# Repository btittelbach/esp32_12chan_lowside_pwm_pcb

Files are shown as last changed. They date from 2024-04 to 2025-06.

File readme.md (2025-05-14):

# esp32_12chan_lowside_pwm_pcb

Open Hardware PCB designed to drive 12 low-side PWM channels.

It's designed to work with e.g. WLED firmware and can drive up to 4 RGB LED strips.

You can however use it for whatever you want.
Free-wheeling diodes were added, in case someone wants to use it to drive bigger inductive loads.

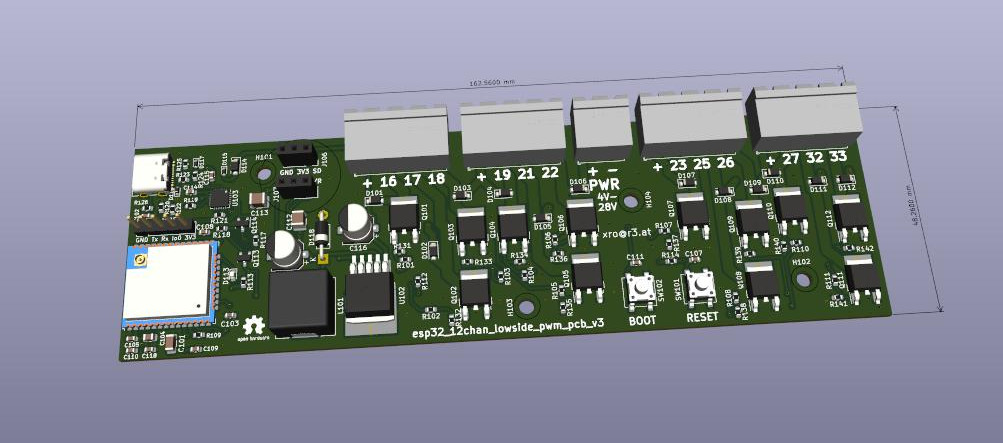
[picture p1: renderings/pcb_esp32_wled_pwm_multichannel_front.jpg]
img_front


[Schematic](renderings/pcb_esp32_wled_pwm_multichannel.pdf)

## Power

### Input

Power by USB for easy flashing.

Or power via screw-terminal: DC from 4V up to 28V.

#### optional Sound-Reactive Microphone Input

- I2S SD pin: gpio4
- I2S WS pin: gpio14
- I2S SCK pin: gpio13

### Output

The four screw terminals each group VDD as well as 4 GPIO controlled PWM-channels to GND.

- terminal 1: VDD, gpio16, gpio17, gpio18
- terminal 2: VDD, gpio19, gpio21, gpio22
- terminal 3: VDD, gpio23, gpio25, gpio26
- terminal 4: VDD, gpio27, gpio32, gpio33

## Firmware

for easy use, flash WLED-ESP32 and use web-interface to configure
4 "LEDS" as RGB-Strips with GPIO pins listed above.

## Manufacturing

the board was not designed to minimize costs, but for durability.

The folder `esp32_12chan_lowside_pwm_pcb_v3` includes all manufacturing files and information,
so you should easily be able to order your own.

See [fabrication_data.md](esp32_12chan_lowside_pwm_pcb_v3/fabrication_data.md) for specs often asked in order to get a quote.

### Expensive Parts
- the MosFETs
- the choosen ESP32, though you may choose a version with less Flash
- the QFN USB to UART bridge
- the buck regulator

### Costs

big price hike in 2025:

- per PCB the parts cost roughly 23 USD
- production+assembly+parts come to roughly 54 USD per PCB

## License

This project is licensed under the CERN OH License - see the [LICENSE](LICENSE.txt) file for details

## Photos

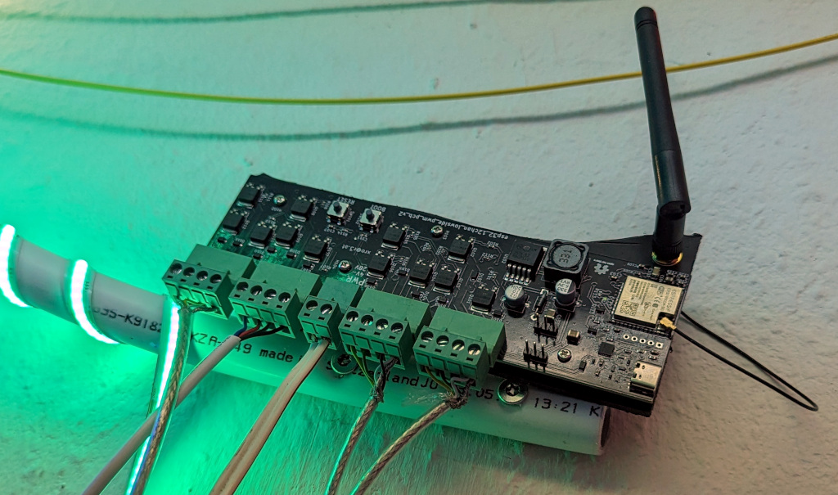
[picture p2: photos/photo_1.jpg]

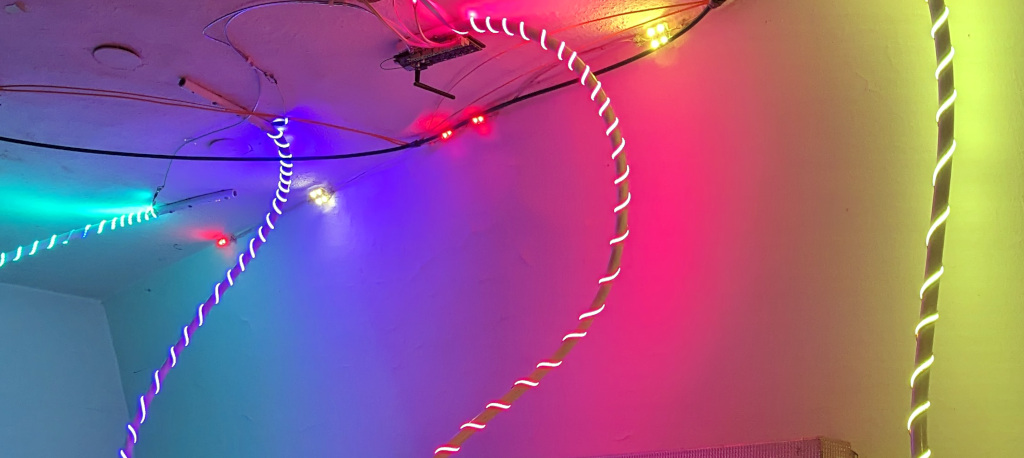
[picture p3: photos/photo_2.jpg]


## Ordering

List of PCB Suppliers which one-click ordering for the board. (so far only one)

- [PCBWay](https://www.pcbway.com/project/shareproject/W18448ASS50_esp32_12chan_wled_pwm_v3_13ab729a.html)

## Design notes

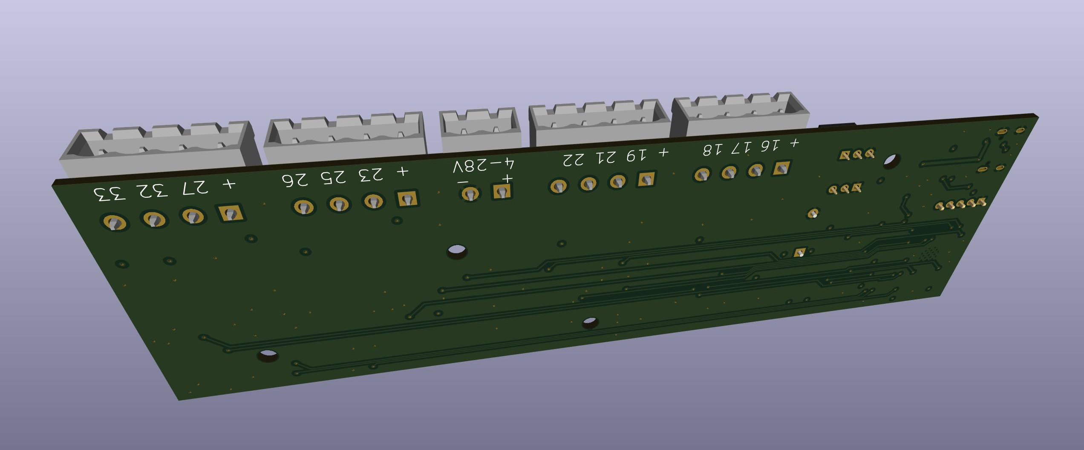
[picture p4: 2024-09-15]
renderings/pcb_esp32_wled_pwm_multichannel_bottom.jpg

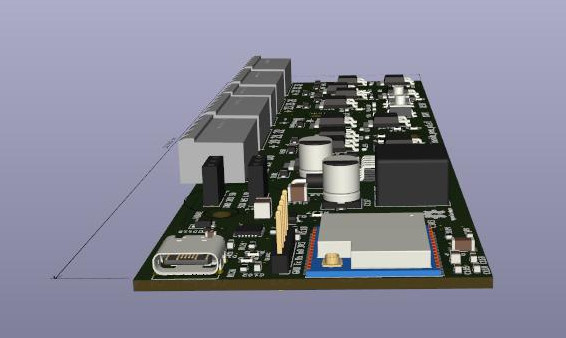
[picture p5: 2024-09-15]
renderings/pcb_esp32_wled_pwm_multichannel_side.jpg

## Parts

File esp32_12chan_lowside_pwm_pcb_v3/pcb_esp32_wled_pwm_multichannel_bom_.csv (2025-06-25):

Reference | Value | Qty | DNP | DNF | Distributor | LCSC | MF | MP | SMD | TH
C101,C102,C103,C104,C105,C106 | CL05A106MQ5NUN | 6 |  |  | LCSC | C15525 | Samsung Electro-Mechanics | CL05A106MQ5NUN | 1
C107 | 100nF/50V | 1 |  |  | LCSC | C42998 | FH | 0603F104M500NT | 1
C111 | 1nF/50V | 1 |  |  | LCSC | C100040 | YAGEO | CC0603KRX7R9BB102 | 1
C112,C113 | 22uF/25V(10%) | 2 |  |  | LCSC | C337455 | Taiyo Yuden | TMK325B7226KM-TR | 1
C116 | 100µF/50V | 1 |  |  | LCSC | C311622 | Lelon | VZT101M1HTR-0607 | 1
C117 | 330µF/6.3V | 1 |  |  | LCSC | C74623 | RVT0J331M0607 | ROQANG | 1
D101,D102,D103,D104,D105,D106,D107,D108,D109,D110,D111,D112,D114 | D_Schottky | 13 |  |  | LCSC | C496544 | Shanghai Prisemi Elec | PSBD1DF40V2L | 1
D113 | GREEN_LED | 1 |  |  | LCSC | C89809 | Foshan NationStar Optoelectronics | NCD0603C3 | 1 | 0
D115,D116,D117 | LESD5D5.0CT1G | 3 |  |  | LCSC | C383211 | LRC | LESD5D5.0CT1G | 1 | 0
D118 | 1N5819 | 1 |  |  |  |  |  |  | 0 | 1
J101,J102,J103,J104 | WJ2EDGRC-5.08-4P | 4 |  |  | LCSC | C8446 | Ningbo Kangnex Elec | WJ2EDGRC-5.08-4P | 0 | 1
J105 | Conn_01x05_Male | 1 |  | DNF |  |  |  |  | 0 | 0
J106,J107 | Conn_01x03_Female | 2 |  |  | LCSC | C358717 | generic | PinHeader,Feamle,P=2.54mm,3Pin,1Row,1A | 0 | 1
J108 | Conn_01x02_Female | 1 |  |  | LCSC | C3697 | Ningbo Kangnex Elec | WJ2EDGRC-5.08-2P | 0 | 1
J109 | USB_C_Receptacle_USB2.0 | 1 |  |  | LCSC | C165948 | Korean Hroparts Elec | TYPE-C-31-M-12 | 1 | 0
L101 | 330µH | 1 |  |  | LCSC | C2929508 | SHOU HAN | CYH127-330UH | 1
Q101,Q102,Q103,Q104,Q105,Q106,Q107,Q108,Q109,Q110,Q111,Q112 | IRLR8743TRPBF | 12 |  |  | LCSC | C3040285 | Infineon Technologies | IRLR8743TRPBF | 1 | 0
Q113,Q114 | Q_NPN_Darlington_BEC | 2 |  |  | LCSC | C164885 | JIANGSU CHANGJIANG ELECTRONICS | SS8050 | 1
R101,R102,R103,R104,R105,R106,R107,R108,R109,R110,R111,R112 | 91(1%) | 12 |  |  |  |  |  |  | 1
R113 | 68Ω/1% | 1 |  |  | LCSC | C126362 | YAGEO | RC0603FR-0768RL | 1 | 0
R114,R117,R118,R121,R131,R132,R133,R134,R135,R136,R137,R138,R139,R140,R141,R142 | 10K(5%) | 16 |  |  |  |  |  |  | 1
R119 | 2K(5%) | 1 |  |  |  |  |  |  | 1 | 0
R120 | 47K(5%) | 1 |  |  |  |  |  |  | 1
R122 | 22K(1%) | 1 |  |  |  |  |  |  | 1
R123,R124 | 22(1%) | 2 |  |  |  |  |  |  | 1
R125,R126 | 5k1 (5%) | 2 |  |  |  |  |  |  | 1 | 0
SW101,SW102 | SW_Push | 2 |  |  | LCSC | C86708 | Omron Electronics | B3SL-1022P | 1
U101 | ESP32-WROOM-32U | 1 |  |  | LCSC | C328062 | Espressif | ESP32-WROOM-32U | 1
U102 | LM2575-3.3BU | 1 |  |  | LCSC | C70337 | onsemi | LM2575D2T-3.3R4G | 1
U103 | CP2102N-Axx-xQFN24 | 1 |  |  | LCSC | C969151 | Silicon Labs | CP2102N-A02-GQFN24R | 1 | 0

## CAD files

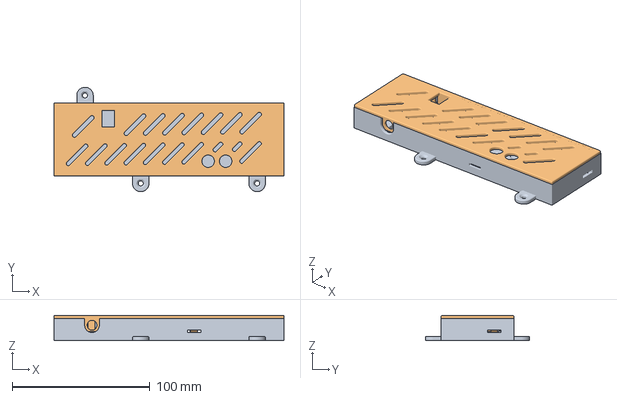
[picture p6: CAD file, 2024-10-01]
enclosure/wled_pwm_multichannel_enclosure_variant_microphone_hole.3mf
167.1 x 75.9 x 18.4 mm

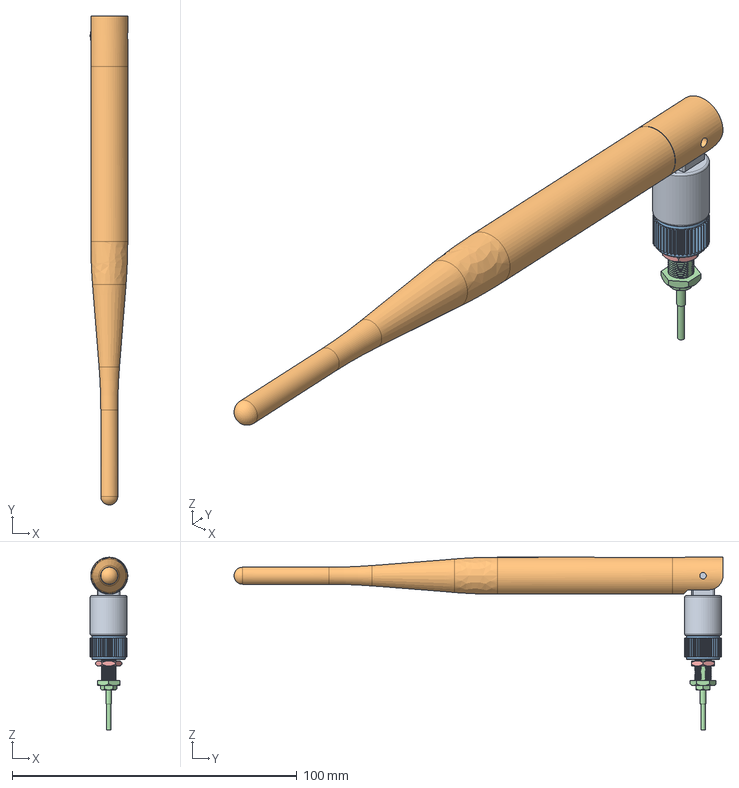
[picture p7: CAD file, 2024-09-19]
enclosure/sma_antenna.FCStd
13.2 x 171.8 x 60.6 mm
antenna_part_2 v2
antenna_part_1 v4
antenna_part_3 v2
SMA_connector_part_1 v3
SMA_connector_part_2 v1

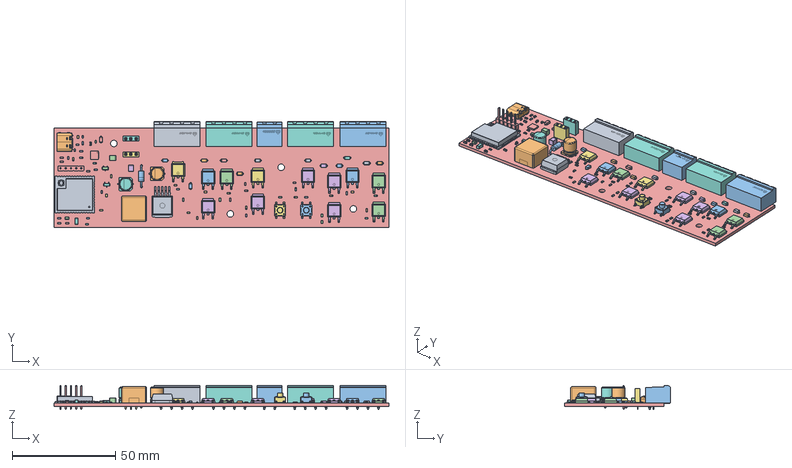
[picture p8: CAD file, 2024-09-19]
enclosure/pcb_esp32_wled_pwm_multichannel_kicad_export.FCStd
162.6 x 51.2 x 11.8 mm
D_SOD_123F
R_0603_1608Metric
SW_SPST_PTS647Sx50
CQ assembly
R_0603_1608Metric002
CQ assembly001
PinSocket_1x03_P254mm_Vertical
PinSocket_1x03_P254mm_Vertical001
R_0603_1608Metric004
R_0603_1608Metric006
D_SOD_523
R_0603_1608Metric008
D_SOD_123F001
CQ assembly002
R_0603_1608Metric010
CP_Elec_63x77
R_0603_1608Metric012
R_0603_1608Metric014
2EDGRC-5.08-04P-14-100AH
C_0603_1608Metric
R_0603_1608Metric016
CQ assembly003
R_0603_1608Metric018
R_0603_1608Metric020
D_SOD_123F002
R_0603_1608Metric022
CQ assembly004
D_SOD_524
C_0603_1608Metric002
R_0603_1608Metric024
R_0603_1608Metric026
C_1206_3216Metric
R_0603_1608Metric028
D_SOD_123F003
D_SOD_123F004
R_0603_1608Metric030
R_0603_1608Metric032
CQ assembly005
C_0603_1608Metric004
C_0603_1608Metric006
C_0603_1608Metric008
CP_Elec_63x078
D_SOD_123F005
R_0603_1608Metric034
R_0603_1608Metric036
CQ assembly006
CQ assembly007
2EDGRC-5.08-04P-14-100AH002
D_SOD_525
L_SXN_SMDRI127
R_0603_1608Metric038
R_0603_1608Metric040
C_0603_1608Metric010
C_0603_1608Metric012
CQ assembly008
C_0603_1608Metric014
C_0603_1608Metric016
R_0603_1608Metric042
CQ assembly009
C_0805_2012Metric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

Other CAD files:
enclosure/wled_pwm_multichannel_enclosure.FCStd
enclosure/wled_pwm_multichannel_enclosure.3mf

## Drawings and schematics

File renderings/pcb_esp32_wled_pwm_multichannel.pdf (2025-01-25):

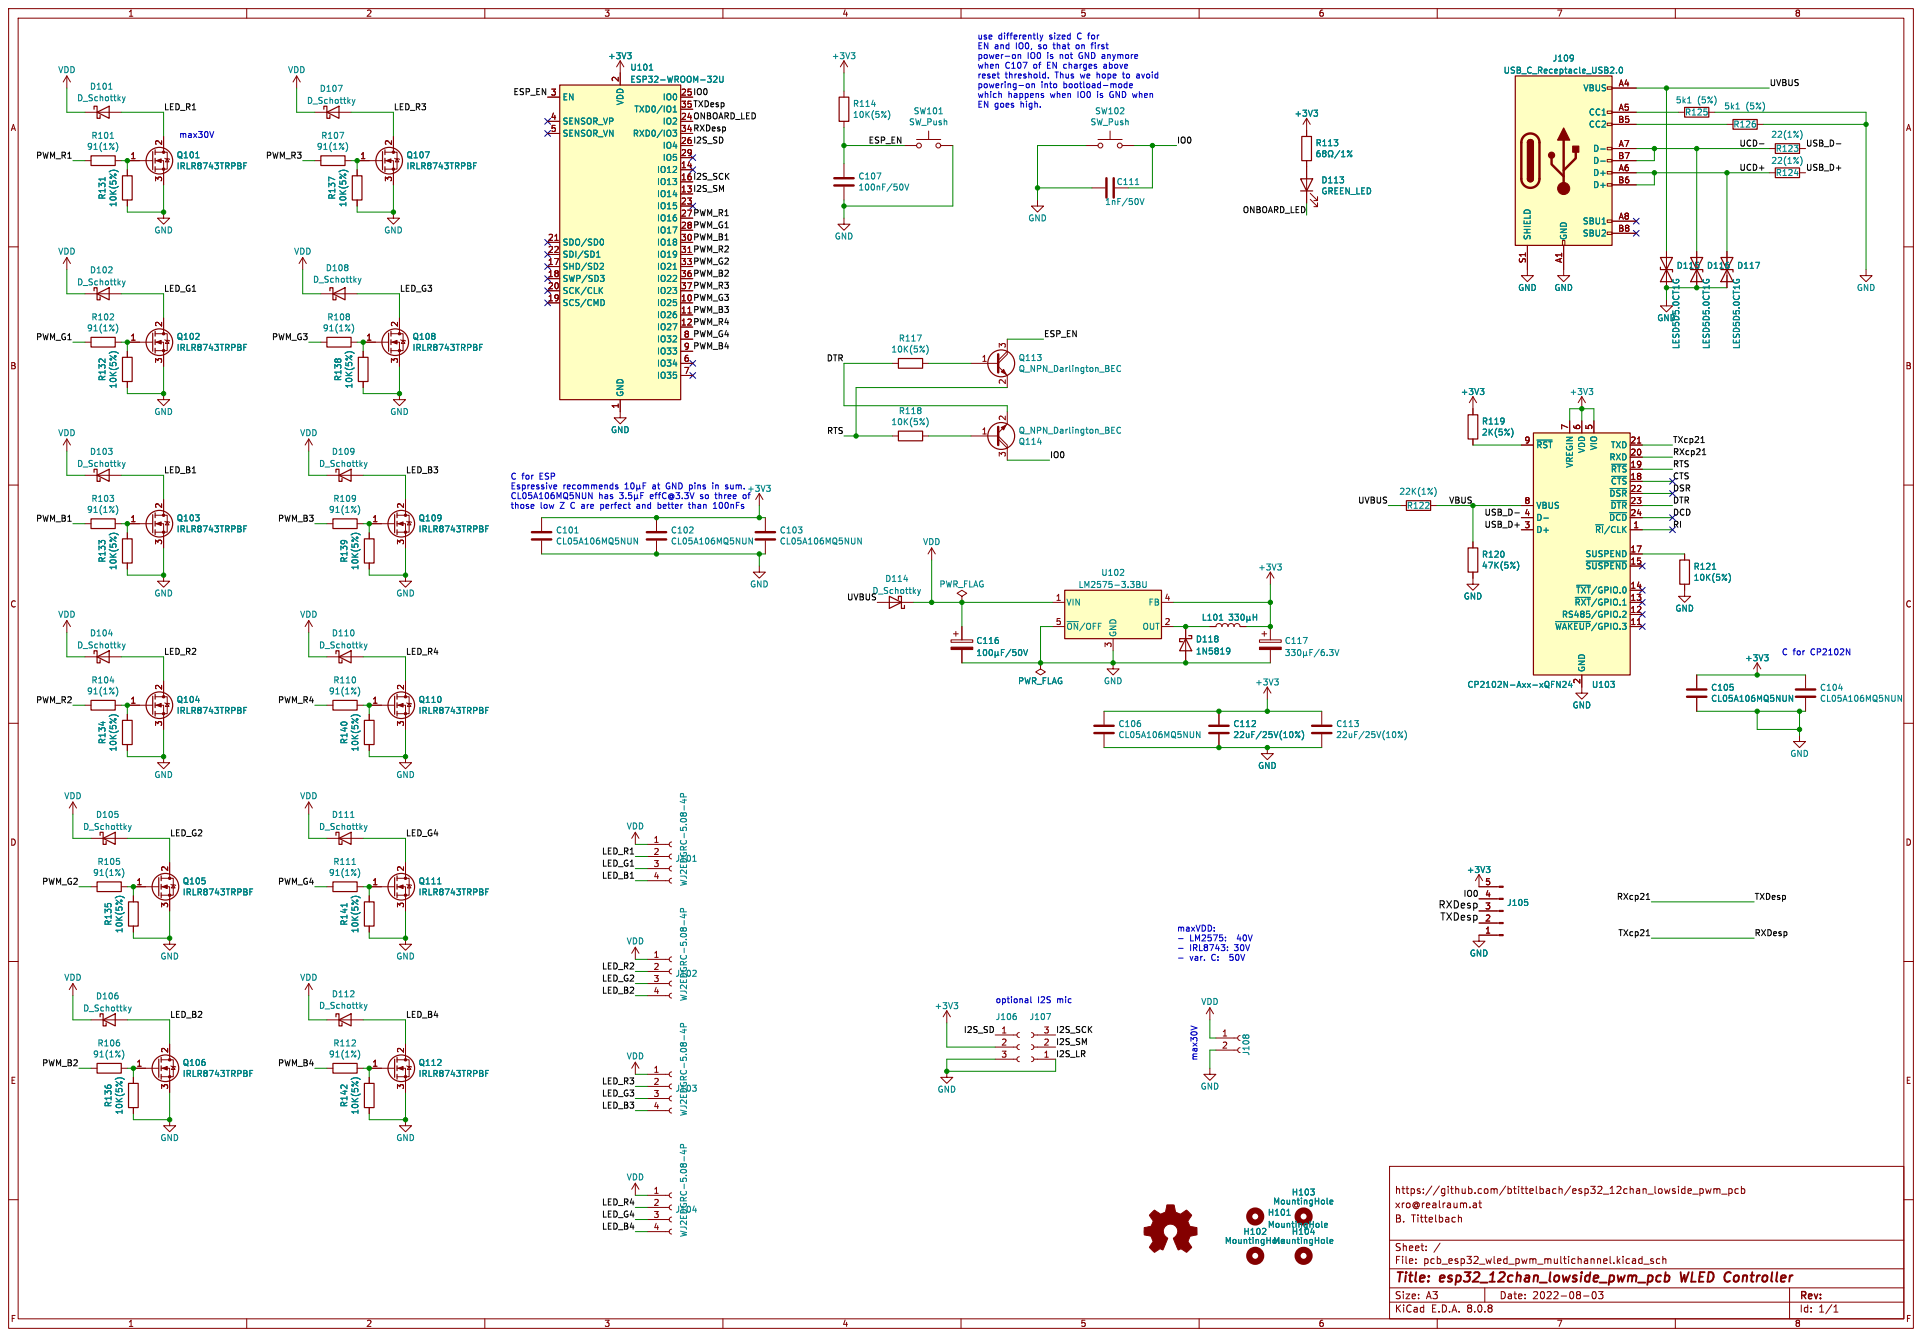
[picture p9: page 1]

2 SCK/CLK 20 SDO/SD0 21 SDI/SD1 22

2 RXD 20 TXD 21 ~{DSR} 22 ~{DTR} 23 ~{DCD} 24 D+ 3 D- 4 VIO

those low Z C are perfect and better than 100nFs

https://github.com/btittelbach/esp32_12chan_lowside_pwm_pcb
xro@realraum.at

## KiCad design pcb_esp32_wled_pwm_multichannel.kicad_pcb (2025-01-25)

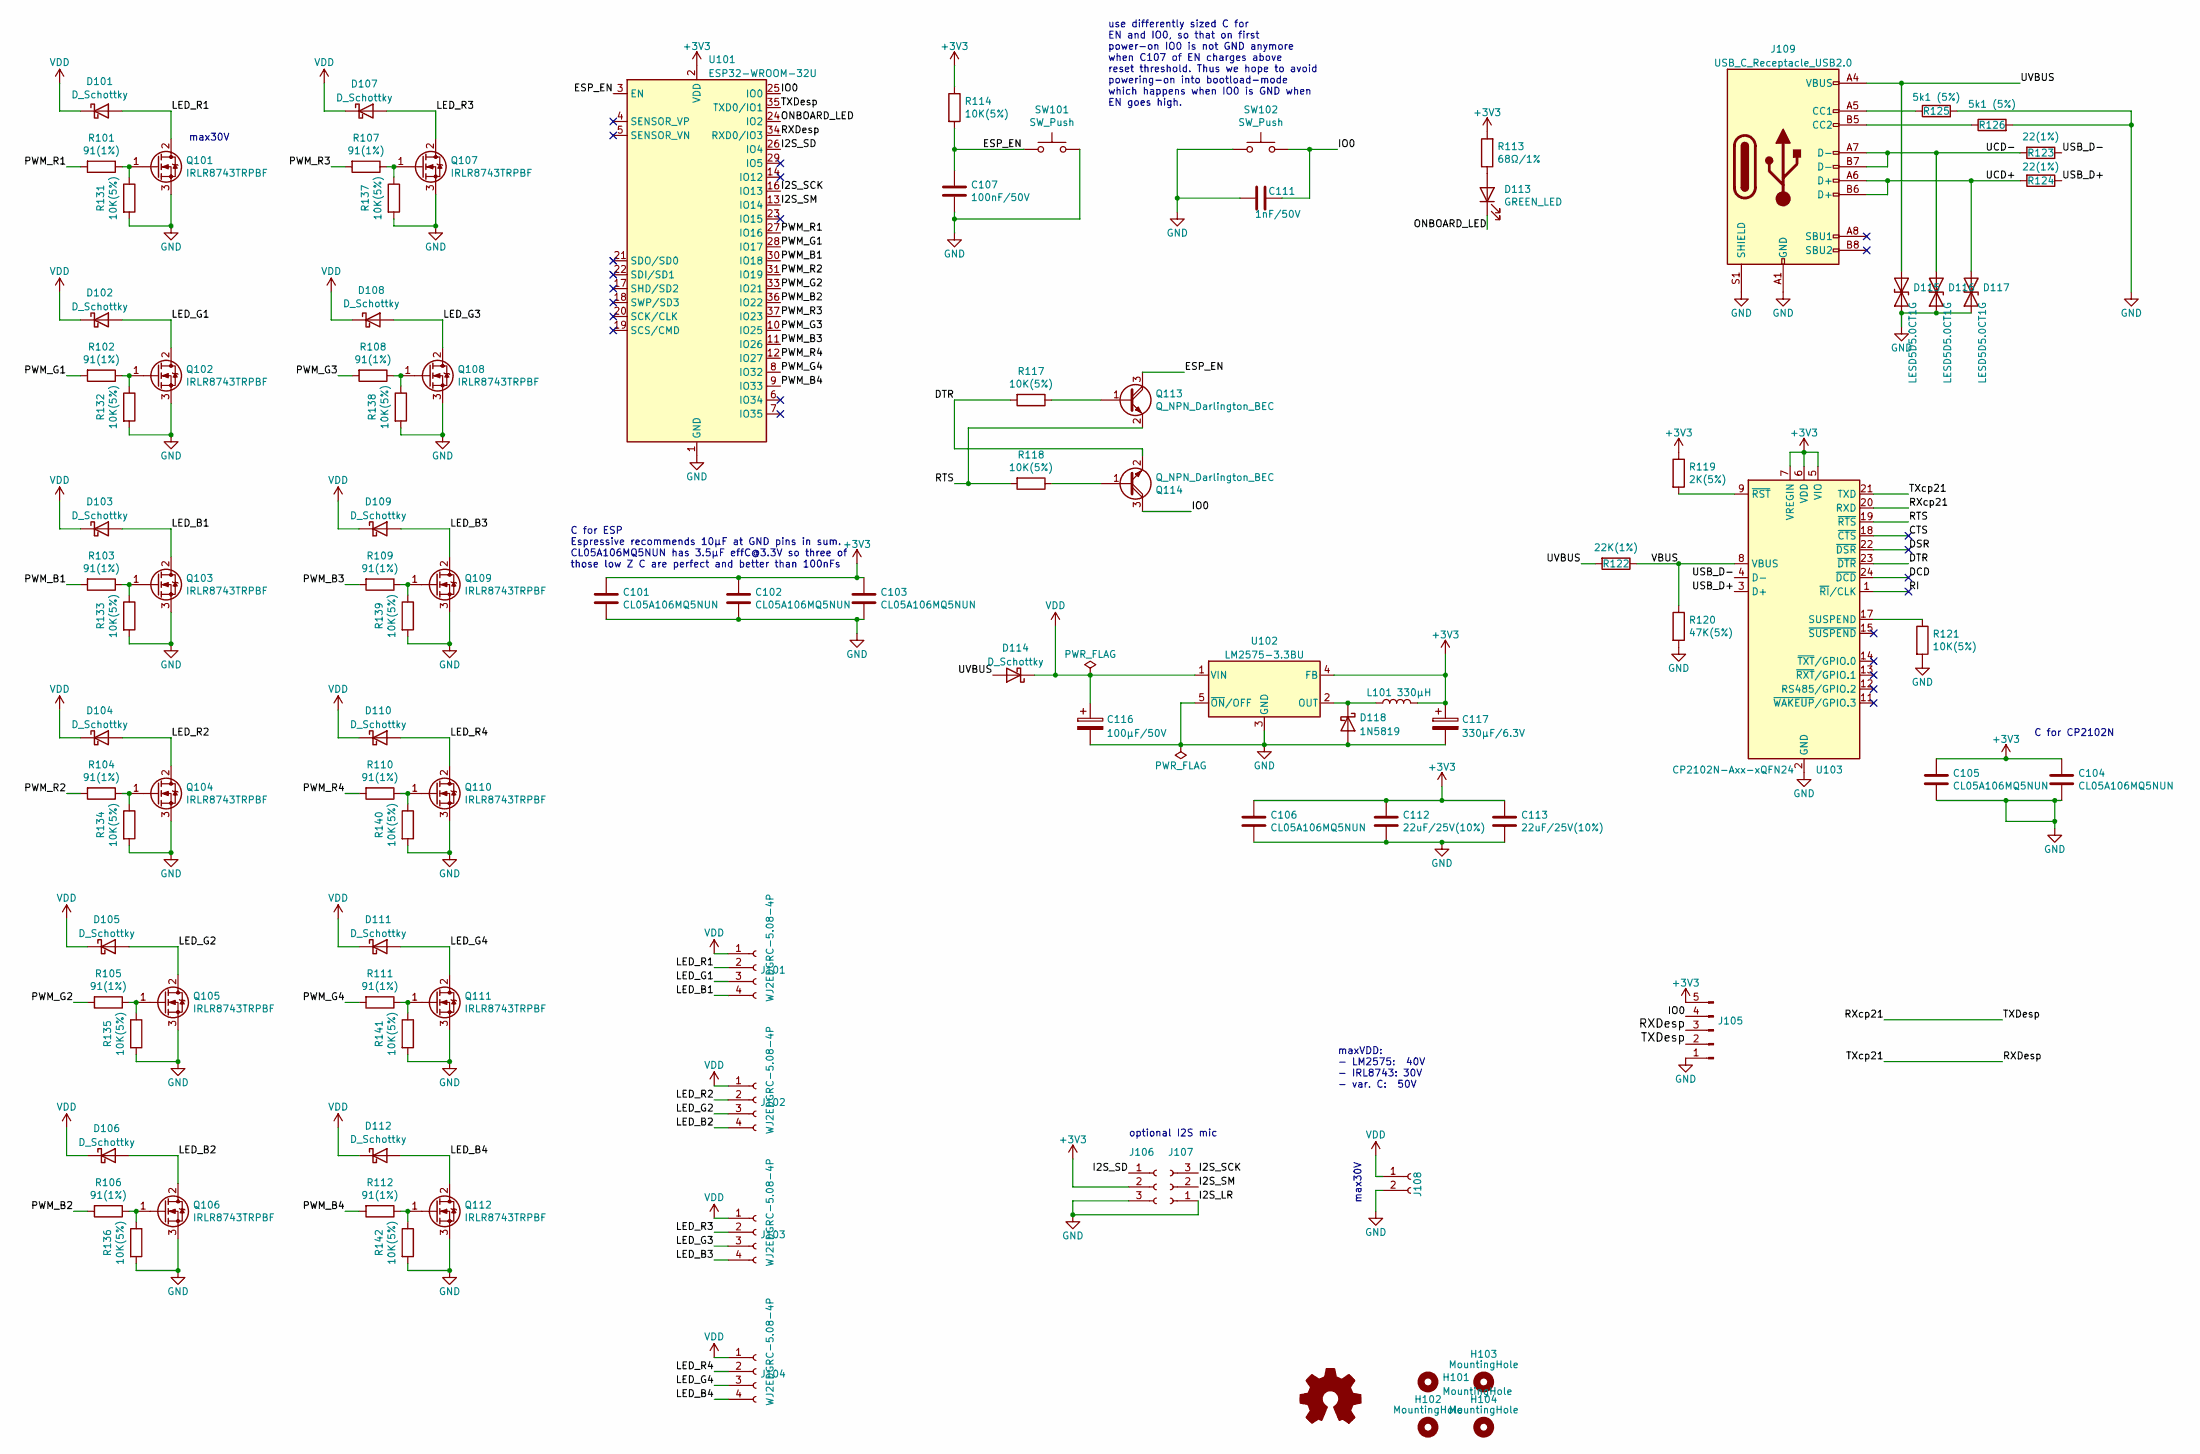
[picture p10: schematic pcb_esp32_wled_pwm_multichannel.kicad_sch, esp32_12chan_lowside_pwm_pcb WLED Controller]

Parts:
C101, C102, C103, C104, C105, C106: CL05A106MQ5NUN; C_0402_1005Metric; LCSC C15525
C107: 100nF/50V; C_0603_1608Metric; LCSC C42998
C111: 1nF/50V; C_0603_1608Metric; LCSC C100040
C112, C113: 22uF/25V(10%); C_1210_3225Metric; LCSC C337455
C116: 100µF/50V; CP_Elec_6.3x7.7; LCSC C311622
C117: 330µF/6.3V; CP_Elec_6.3x7.7; LCSC C74623
D101, D102, D103, D104, D105, D106, D107, D108, D109, D110, D111, D112, D114: D_Schottky; D_SOD-123F; LCSC C496544
D113: GREEN_LED; LED_0603_1608Metric; LCSC C89809
D115, D116, D117: LESD5D5.0CT1G; D_SOD-523; LCSC C383211
D118: 1N5819; D_DO-41_SOD81_P10.16mm_Horizontal
H101, H102, H103, H104: MountingHole; MountingHole_3.2mm_M3_ISO7380
J101, J102, J103, J104: WJ2EDGRC-5.08-4P; 2EDGRC-5.08-04P-14-100AH; LCSC C8446
J105: Conn_01x05_Male; PinHeader_1x05_P2.54mm_Vertical
J106, J107: Conn_01x03_Female; PinSocket_1x03_P2.54mm_Vertical; LCSC C358717
J108: Conn_01x02_Female; 2EDGRC-5.08-02P-14-100AH; LCSC C3697
J109: USB_C_Receptacle_USB2.0; USB_C_Receptacle_CIKI_TYPE-C-2.0-16PIN-SMT-3; LCSC C2987386
L101: 330µH; L_12x12mm_H8mm; LCSC C2929508
Q101, Q102, Q103, Q104, Q105, Q106, Q107, Q108, Q109, Q110, Q111, Q112: IRLR8743TRPBF; TO-252-2; LCSC C3040285
Q113, Q114: Q_NPN_Darlington_BEC; SOT-23; LCSC C164885
R101, R102, R103, R104, R105, R106, R107, R108, R109, R110, R111, R112: 91(1%); R_0603_1608Metric
R113: 68Ω/1%; R_0603_1608Metric; LCSC C126362
R114, R117, R118, R121, R131, R132, R133, R134, R135, R136, R137, R138, R139, R140, R141, R142: 10K(5%); R_0603_1608Metric
R119: 2K(5%); R_0603_1608Metric
R120: 47K(5%); R_0603_1608Metric
R122: 22K(1%); R_0603_1608Metric
R123, R124: 22(1%); R_0603_1608Metric
R125, R126: 5k1 (5%); R_0603_1608Metric
SW101, SW102: SW_Push; SW_SPST_B3SL-1022P; LCSC C86708
SYM101: Logo_Open_Hardware_Small; OSHW-Logo2_7.3x6mm_SilkScreen
U101: ESP32-WROOM-32U; LCSC C328062
U102: LM2575-3.3BU; TO-263-5_TabPin3; LCSC C70337
U103: CP2102N-Axx-xQFN24; QFN-24-1EP_4x4mm_P0.5mm_EP2.6x2.6mm; LCSC C969151

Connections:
+3V3: C101.1, C102.1, C103.1, C104.1, C105.1, C106.1, C112.1, C113.1, C117.1, J105.5, J106.2, L101.2, R113.2, R114.1, R119.1, U101.2 (VDD), U102.4 (FB), U103.5 (VIO), U103.6 (VDD), U103.7 (VREGIN)
/CTS: U103.18 (~CTS)
/DCD: U103.24 (~DCD)
/DSR: U103.22 (~DSR)
/DTR: Q114.2 (E), R117.2, U103.23 (~DTR)
/ESP_EN: C107.1, Q113.3 (C), R114.2, SW101.1, U101.3 (EN)
/I2S_SCK: J107.3, U101.16 (IO13)
/I2S_SD: J106.1, U101.26 (IO4)
/I2S_SM: J107.2, U101.13 (IO14)
/IO0: C111.1, J105.4, Q114.3 (C), SW102.2, U101.25 (IO0)
/LED_B1: D103.2 (A), J101.4, Q103.2 (D)
/LED_B2: D106.2 (A), J102.4, Q106.2 (D)
/LED_B3: D109.2 (A), J103.4, Q109.2 (D)
/LED_B4: D112.2 (A), J104.4, Q112.2 (D)
/LED_G1: D102.2 (A), J101.3, Q102.2 (D)
/LED_G2: D105.2 (A), J102.3, Q105.2 (D)
/LED_G3: D108.2 (A), J103.3, Q108.2 (D)
/LED_G4: D111.2 (A), J104.3, Q111.2 (D)
/LED_R1: D101.2 (A), J101.2, Q101.2 (D)
/LED_R2: D104.2 (A), J102.2, Q104.2 (D)
/LED_R3: D107.2 (A), J103.2, Q107.2 (D)
/LED_R4: D110.2 (A), J104.2, Q110.2 (D)
/ONBOARD_LED: D113.1 (K), U101.24 (IO2)
/PWM_B1: R103.2, U101.30 (IO18)
/PWM_B2: R106.2, U101.36 (IO22)
/PWM_B3: R109.2, U101.11 (IO26)
/PWM_B4: R112.2, U101.9 (IO33)
/PWM_G1: R102.2, U101.28 (IO17)
/PWM_G2: R105.2, U101.33 (IO21)
/PWM_G3: R108.2, U101.10 (IO25)
/PWM_G4: R111.2, U101.8 (IO32)
/PWM_R1: R101.2, U101.27 (IO16)
/PWM_R2: R104.2, U101.31 (IO19)
/PWM_R3: R107.2, U101.37 (IO23)
/PWM_R4: R110.2, U101.12 (IO27)
/RI: U103.1 (~RI/CLK)
/RTS: Q113.2 (E), R118.2, U103.19 (~RTS)
/RXDesp: J105.3, U101.34 (RXD0/IO3), U103.21 (TXD)
/RXcp21: J105.2, U101.35 (TXD0/IO1), U103.20 (RXD)
/UCD+: D117.2 (A2), J109.A6 (D+), J109.B6 (D+), R124.2
/UCD-: D116.2 (A2), J109.A7 (D-), J109.B7 (D-), R123.2
/USB_D+: R124.1, U103.3 (D+)
/USB_D-: R123.1, U103.4 (D-)
/UVBUS: D114.2 (A), D115.2 (A2), J109.A4 (VBUS), J109.A9 (VBUS), J109.B4 (VBUS), J109.B9 (VBUS), R122.2
/VBUS: R120.1, R122.1, U103.8 (VBUS)
GND: C101.2, C102.2, C103.2, C104.2, C105.2, C106.2, C107.2, C111.2, C112.2, C113.2, C116.2, C117.2, D115.1 (A1), D116.1 (A1), D117.1 (A1), D118.2 (A), J105.1, J106.3, J107.1, J108.2, J109.A1 (GND), J109.A12 (GND), J109.B1 (GND), J109.B12 (GND), J109.S1 (SHIELD), Q101.3 (S), Q102.3 (S), Q103.3 (S), Q104.3 (S), Q105.3 (S), Q106.3 (S), Q107.3 (S), Q108.3 (S), Q109.3 (S), Q110.3 (S), Q111.3 (S), Q112.3 (S), R120.2, R121.2, R125.2, R126.2, R131.2, R132.2, R133.2, R134.2, R135.2, R136.2, R137.2, R138.2, R139.2, R140.2, R141.2, R142.2, SW101.2, SW102.1, U101.1 (GND), U101.15 (GND), U101.38 (GND), U101.39 (GND), U102.3 (GND), U102.5 (~ON/OFF), U103.2 (GND), U103.25 (GND)
unnamed: D113.2 (A), R113.1
unnamed: D118.1 (K), L101.1, U102.2 (OUT)
unnamed: J109.A5 (CC1), R125.1
unnamed: J109.B5 (CC2), R126.1
unnamed: Q101.1 (G), R101.1, R131.1
unnamed: Q102.1 (G), R102.1, R132.1
unnamed: Q103.1 (G), R103.1, R133.1
unnamed: Q104.1 (G), R104.1, R134.1
unnamed: Q105.1 (G), R105.1, R135.1
unnamed: Q106.1 (G), R106.1, R136.1
unnamed: Q107.1 (G), R107.1, R137.1
unnamed: Q108.1 (G), R108.1, R138.1
unnamed: Q109.1 (G), R109.1, R139.1
unnamed: Q110.1 (G), R110.1, R140.1
unnamed: Q111.1 (G), R111.1, R141.1
unnamed: Q112.1 (G), R112.1, R142.1
unnamed: Q113.1 (B), R117.1
unnamed: Q114.1 (B), R118.1
unnamed: R121.1, U103.17 (SUSPEND)
unnamed: R119.2, U103.9 (~RST)
VDD: C116.1, D101.1 (K), D102.1 (K), D103.1 (K), D104.1 (K), D105.1 (K), D106.1 (K), D107.1 (K), D108.1 (K), D109.1 (K), D110.1 (K), D111.1 (K), D112.1 (K), D114.1 (K), J101.1, J102.1, J103.1, J104.1, J108.1, U102.1 (VIN)

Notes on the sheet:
use differently sized C for EN and IO0, so that on first power-on IO0 is not GND anymore when C107 of EN charges above reset threshold. Thus we hope to avoid powering-on into bootload-mode which happens when IO0 is GND when EN goes high.
maxVDD: - LM2575: 40V - IRL8743: 30V - var. C: 50V
C for ESP Espressive recommends 10μF at GND pins in sum. CL05A106MQ5NUN has 3.5μF effC@3.3V so three of those low Z C are perfect and better than 100nFs
optional I2S mic
max30V
C for CP2102N

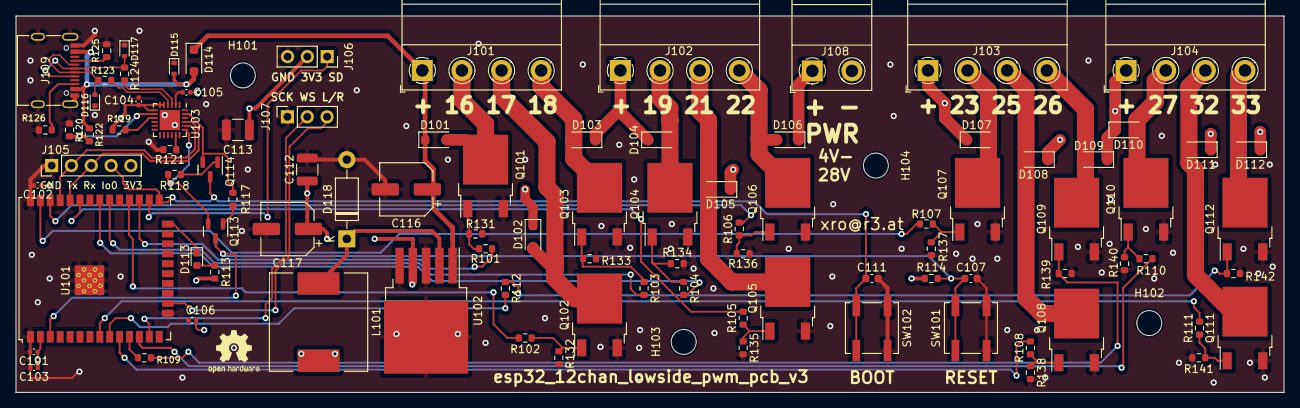
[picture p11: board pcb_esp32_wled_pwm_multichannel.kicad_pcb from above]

Board: 4 copper layers, 162.6 x 48.3 mm, 100 parts (0 on the bottom side), 63 nets.

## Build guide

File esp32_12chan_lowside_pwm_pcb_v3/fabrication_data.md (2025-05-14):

# PCB

- Size: 162.6mm x 48.3mm
- Layer: 4
- Layer Order: F, In1, In2, B
- Material: FR-4
- Thickness: 1.6mm
- Outter Copper: 1oz-2oz Cu
- Inner Copper: 1oz Cu
- Min Hole Size: 0.2

# Assembly

- Top-Side only
- Number of unique Parts:	32
- Fitted Components:	87
- Number SMD Parts:	28
- Number of BGA/QFP Parts: 0
- Number TH Parts:	4

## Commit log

2023-01-30 final cleaned v2 PCB
    [12channel_wled_pwm_pcb.FCStd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]
2023-02-02 change footprint of polarized C to larger version that actually exists. Update BOM
    [pcb_esp32_wled_pwm_multichannel-B_Cu.gbr, pcb_esp32_wled_pwm_multichannel-B_Mask.gbr, pcb_esp32_wled_pwm_multichannel-B_Paste.gbr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]
2023-03-24 fix description of C117
    [pcb_esp32_wled_pwm_multichannel.kicad_sch, pcb_esp32_wled_pwm_multichannel_bom_.xlsx]
2023-04-03 fix I2S microphone pin header. V3
    [pcb_esp32_wled_pwm_multichannel-B_Cu.gbr, pcb_esp32_wled_pwm_multichannel-B_Mask.gbr, pcb_esp32_wled_pwm_multichannel-B_Paste.gbr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]
2023-08-27 update future v3: reduce capacity of C111 debouncing BOOT0/IO0, so we are less likely to enter bootloader-mode on power-up
    [pcb_esp32_wled_pwm_multichannel-B_Cu.gbr, pcb_esp32_wled_pwm_multichannel-B_Mask.gbr, pcb_esp32_wled_pwm_multichannel-B_Paste.gbr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]
2023-08-27 label as v3 on silkscreen
    [pcb_esp32_wled_pwm_multichannel-B_Cu.gbr, pcb_esp32_wled_pwm_multichannel-B_Mask.gbr, pcb_esp32_wled_pwm_multichannel-B_Paste.gbr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]
2023-08-30 several fixes, thanks to mickdermack for reviewing
    [pcb_esp32_wled_pwm_multichannel-B_Cu.gbr, pcb_esp32_wled_pwm_multichannel-B_Mask.gbr, pcb_esp32_wled_pwm_multichannel-B_Paste.gbr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]
2023-09-07 wip: re-add 10ks discharge R to MosFETs
    [pcb_esp32_wled_pwm_multichannel.kicad_pcb, pcb_esp32_wled_pwm_multichannel.kicad_sch]
2023-09-08 v3 release version: improved routing, closer C, WIP discharge-R done, new renderings, new gerber
    [pcb_esp32_wled_pwm_multichannel-B_Cu.gbr, pcb_esp32_wled_pwm_multichannel-B_Mask.gbr, pcb_esp32_wled_pwm_multichannel-B_Paste.gbr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]
2024-09-11 PCB Enclosure v0.8
    [pcb_esp32_wled_pwm_multichannel_kicad_export.FCStd, sma_antenna.FCStd, wled_pwm_multichannel_enclosure.3mf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]
2024-09-11 update to kicad v8.0 format
    [pcb_esp32_wled_pwm_multichannel.kicad_pcb, pcb_esp32_wled_pwm_multichannel.kicad_sch]
2024-09-14 enclosure fixes
    [wled_pwm_multichannel_enclosure.3mf, wled_pwm_multichannel_enclosure.FCStd]
2024-09-15 enclosure: fix height
    [pcb_esp32_wled_pwm_multichannel_kicad_export.FCStd, sma_antenna.FCStd, wled_pwm_multichannel_enclosure.FCStd]
2024-09-15 enclosure: fix lid
    [wled_pwm_multichannel_enclosure.FCStd]
2024-09-15 enclosure: recduce pcb tolerance offset
    [wled_pwm_multichannel_enclosure.FCStd]
2024-09-15 enclosure: fix clips
    [wled_pwm_multichannel_enclosure.FCStd]
2024-09-15 enclosure: make space for capacities
    [wled_pwm_multichannel_enclosure.FCStd]
2024-09-15 enclosure: added slots for degson clips
    [wled_pwm_multichannel_enclosure.3mf, wled_pwm_multichannel_enclosure.FCStd]
2024-09-15 enclosure: remove old
    [12channel_wled_pwm_pcb.FCStd]
2024-09-18 increase height tolerances. more space for th-pins. more space for optional microphone.
    [wled_pwm_multichannel_enclosure.FCStd]
2024-09-18 fix clips and notches. Carve out corners for printers that tend to round in hard edges.
    [wled_pwm_multichannel_enclosure.FCStd]
2024-09-18 enlosure: add pin labels
    [sma_antenna.FCStd, wled_pwm_multichannel_enclosure.3mf, wled_pwm_multichannel_enclosure.FCStd]
2024-09-19 enclosure: configure inscription depth
    [pcb_esp32_wled_pwm_multichannel_kicad_export.FCStd, sma_antenna.FCStd]
2024-09-30 re-export to 3mf
    [wled_pwm_multichannel_enclosure.3mf]
2024-10-01 enclosure variant
    [wled_pwm_multichannel_enclosure_variant_microphone_hole.3mf]
2025-01-08 fix one pdf link
    [pcb_esp32_wled_pwm_multichannel.kicad_sch]
2025-01-25 v3.1 change Cs
    [pcb_esp32_wled_pwm_multichannel-B_Cu.gbr, pcb_esp32_wled_pwm_multichannel-B_Mask.gbr, pcb_esp32_wled_pwm_multichannel-B_Paste.gbr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]
2025-05-13 USB-C plug replacement
    [pcb_esp32_wled_pwm_multichannel.kicad_sch, pcb_esp32_wled_pwm_multichannel_bom_.csv]
2025-06-25 re-export BOM and remove KiCAD-symbol-description which confuses PCB supplier
    [pcb_esp32_wled_pwm_multichannel_bom_.csv]
